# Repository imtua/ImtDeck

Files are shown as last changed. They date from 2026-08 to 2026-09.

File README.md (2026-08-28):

# ImtDeck - Your own Cyberdeck

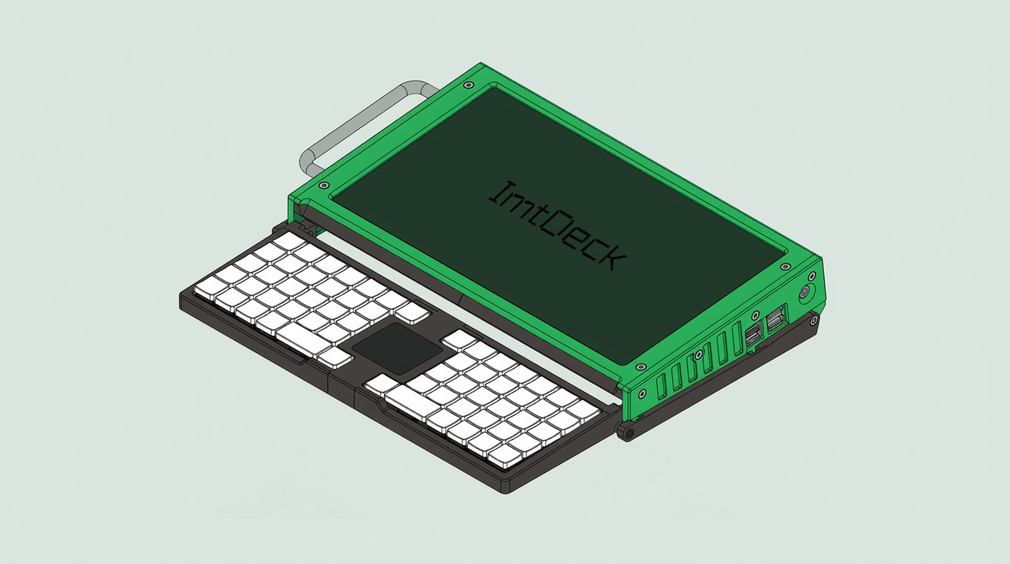
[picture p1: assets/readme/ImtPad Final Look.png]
Final Look of ImtDeck


ImtDeck, a cyberdeck designed by **Imtiaz Ahmed**. In ImtDeck, basic tasks and a light AI can be run easily. In this project, it technically contains 2 projects, **ImtDeck-Carrier** and **ImtKeeb-Ortho62**.

**Stardance** project: https://stardance.hackclub.com/projects/54966

# Wanted Ingredients to craft ImtDeck
## Main items-
- **Lattepanda MU + Carrier + Active Cooler** - $250.00 - 1
- **11.6 Inch Screen** - $129.00 - 1
- **Antenna** - $7.99 - 1
- **Audio Card from Waveshare** - $51.71 - 1
- **KAILH Linear Low Profile Switches** - $56.82 - 3
- **Chosfox CFX BoW Keycap Set** - $33.00 - 1
- **TPS43-201A-S** - $13.87 - 1
- **Power Bank** - $13.00 - 1
- **WIFI Card** - $28.00 - 1
- **Pi Pico** - $12.00 - 1
- **USB Micro Cord** - $13.00 - 1
- **40MM Speaker** - $6.00 - 1
- **Tiny SSD** - $70.00 - 1

Check <a href="https://github.com/imtua/ImtDeck/blob/main/ImtDeck%20BOM.csv"><b>ImtDeck BOM.csv</b></a> for links.

## Hardwares-
- 4x M4 Threaded heat-set brass inserts
- 26x M3 Threaded heat-set brass inserts
- 6x M3x8mm Tapered head bolts
- 8x M3x12mm Tapered head bolts
- 4x M3x8mm Socket head bolts
- 4x M3x10mm Socket head bolts
- 2x M4x14mm Socket head bolts
- 2x M4x16mm Socket head bolts
- 2x M4x24mm Socket head bolts
- 1x 7mm OD Carbon fiber rod, 310mm long (can be any material)
- 2x 6.5x2.5mm neodymium magnets (optional)
- 1x Cabinet handle with 4-inch spacing between ends (optional)

# ImtKeeb-Ortho62 - Designed Keyboard for ImtDeck
**ImtKeeb-Ortho62** is a low-profile ortholinear 62 key keyboard that contains a trackpad in it.

**PCB of ImtKeeb-Ortho62:**

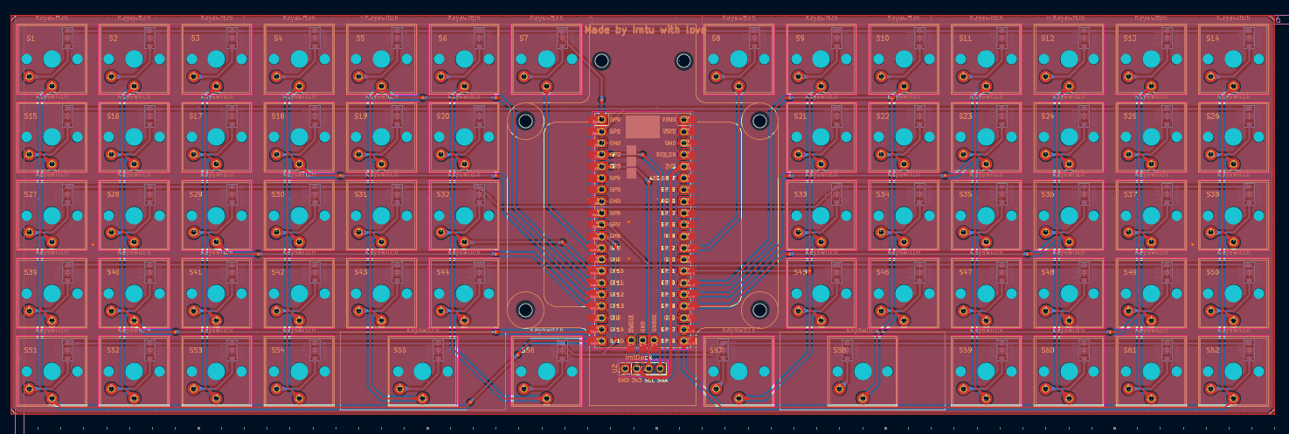
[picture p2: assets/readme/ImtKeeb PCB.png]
PCB of ImtKeeb-Ortho62


**3D PCB of ImtKeeb-Ortho62:**

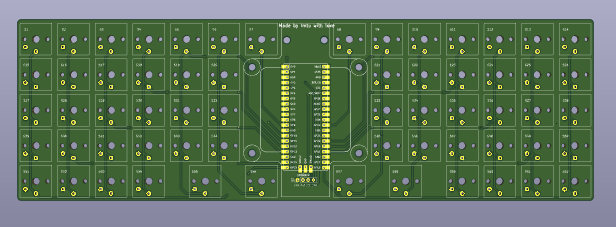
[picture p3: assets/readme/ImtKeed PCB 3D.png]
3D PCB of ImtKeeb-Ortho62


**ImtKeeb-Ortho62 will feature-**
- <a href="https://www.amazon.com/dp/B0B3MN1ZLW"><b>KAILH Low Profile Switch 1350 Chocolate</b></a> - 62 Switches.
- <a href="https://chosfox.com/collections/keycaps/products/chocfox-bow"><b>Chosfox CFX BoW Keycap Set</b></a> - 62 Keycaps.
- <a href="https://www.digikey.com/en/products/detail/azoteq-pty-ltd/TPS43-201A-S/7164940"><b>TPS43-201A-S</b></a> Trackpad.
- <a href="https://store.roboticsbd.com/raspberry-pi/1599-raspberry-pi-pico-robotics-bangladesh.html"><b>Raspberry Pi Pico</b></a> - Brain of the ImtKeeb-Ortho62.

**Files of ImtKeeb-Ortho62**
- <a href="https://github.com/imtua/ImtDeck/blob/main/production/ImtKeeb-Ortho62/ImtKeeb-Ortho62%20Gerber.zip"><b>ImtKeeb-Ortho62 Gerber Files</a></b> - **/Production/ImtKeeb-Ortho62/ImtKeeb-Ortho62 Gerber.zip**
- <a href="https://github.com/imtua/ImtDeck/blob/main/PCB/ImtKeeb-Ortho62/ImtKeed-Ortho62.kicad_sch"><b>ImtKeeb-Ortho62 Schematics</a><b> - **/PCB/ImtKeeb-Ortho62/ImtKeed-Ortho62.kicad_sch**
- <a href="https://github.com/imtua/ImtDeck/blob/main/PCB/ImtKeeb-Ortho62/ImtKeeb-Ortho62.kicad_pcb"><b>ImtKeeb-Ortho62 PCB</a></b> - **/PCB/ImtKeeb-Ortho62/ImtKeed-Ortho62.kicad_pcb**
- <a href="https://github.com/imtua/ImtDeck/tree/main/QMK"><b>Keyboard QMK config files</b></a> - /QMK

This can be used without the ImtDeck.

# ImtDeck-Carrier - Carrier for MU LattePanda
**ImtDeck-Carrier** is a carrier that holds the lattepanda and makes it route and connect to devices like the monitor, fan, keyboard etc.

**Schematic of ImtDeck-Carrier:**

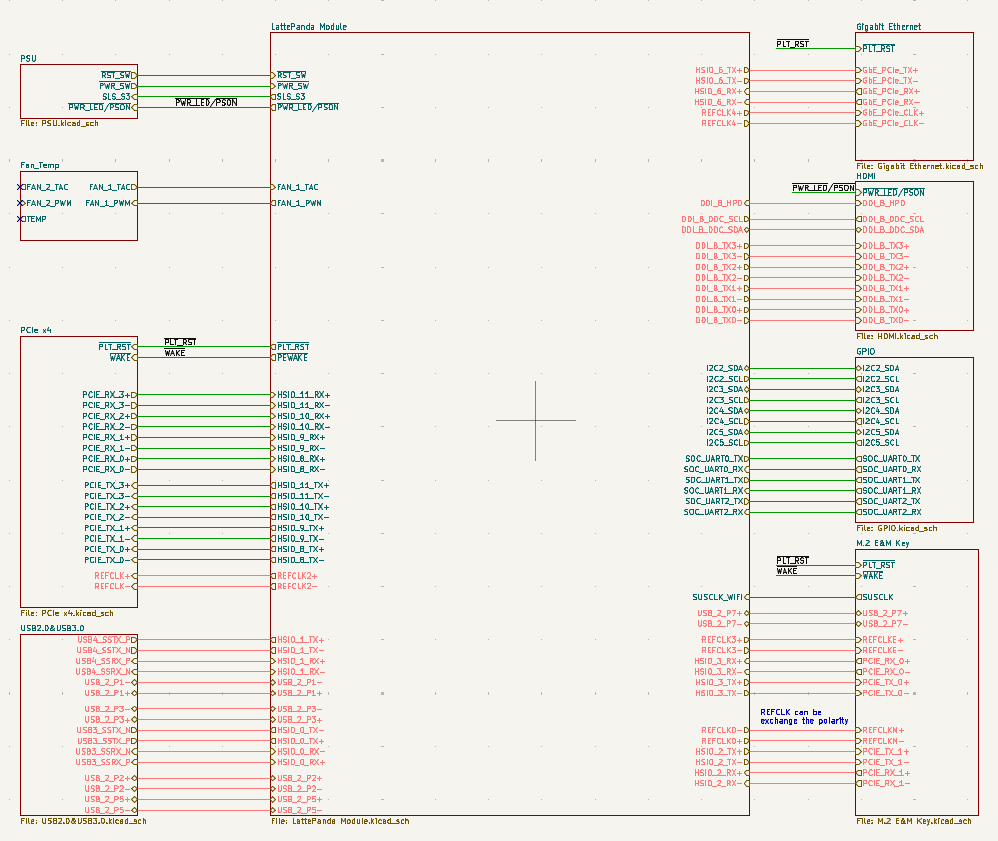
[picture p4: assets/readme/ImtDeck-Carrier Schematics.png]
Schematic of ImtDeck-Carrier


**PCB of ImtDeck-Carrier:**

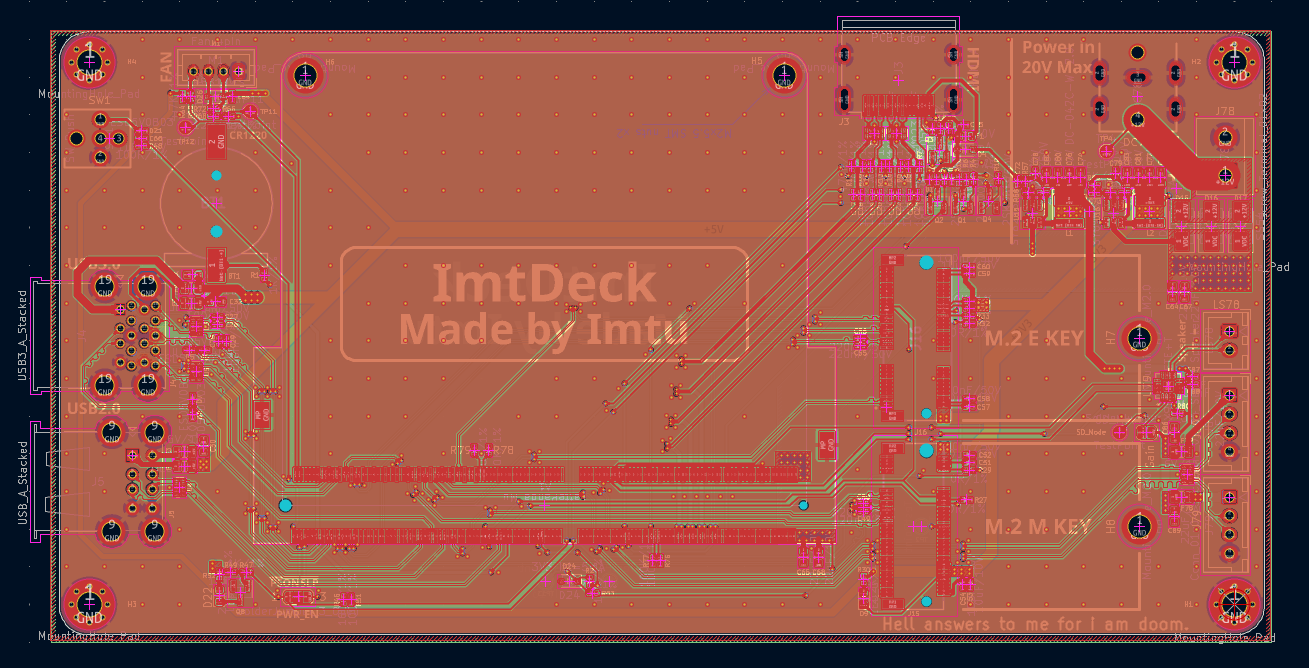
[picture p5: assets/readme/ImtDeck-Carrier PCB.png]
PCB of ImtDeck-Carrier


**ImtDeck-Carrier** will hold the Lattepanda MU in its place and will distribute powers between items. 

**Files of ImtKeeb-Ortho62**
- <a href="https://github.com/imtua/ImtDeck/blob/main/production/ImtDeck-Carrier/ImtDeck-Carrier%20Gerber.zip"><b>ImtDeck-Carrier Gerber Files</a></b> - **/Production/ImtDeck-Carrier/ImtDeck-Carrier Gerber.zip**
- <a href="https://github.com/imtua/ImtDeck/blob/main/PCB/ImtDeck-Carrier/ImtDeck-Carrier.kicad_sch"><b>ImtDeck-Carrier Schematics</a><b> - **/PCB/ImtDeck-Carrier/ImtDeck-Carrier.kicad_sch**
- <a href="https://github.com/imtua/ImtDeck/blob/main/PCB/ImtDeck-Carrier/ImtDeck-Carrier.kicad_pcbb"><b>ImtDeck-Carrier PCB</a></b> - **/PCB/ImtDeck-Carrier/ImtDeck-Carrier.kicad_pcb**

# Features
- ImtDeck will feature Linux Mint OS in it.
- With it, you can access different tools and a lightweight offline AI in it.
- All ready-to-go device.
- Can play low-end games on it.
- Features Keyboard and Trackpad.
- Sound System.
- Can run everything a normal laptop can.

# Conclusion

Made by <a href="https://github.com/imtua"><b>Imtiaz</b></a> with the help of <a href="https://hackclub.com"><b>Hack Club</a></b>

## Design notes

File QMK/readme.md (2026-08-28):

# ImtKeeb-Ortho62

*This keyboard was designed for use in ImtDeck. can be used without ImtDeck, not for business purposes.

* Keyboard Maintainer: [Imtiaz Ahamed](https://github.com/imtua)
* Hardware Supported: *Pi-Pico/RP2040*
* Hardware Availability: Any Hardware Shop.

Make example for this keyboard (after setting up your build environment):

    make imtkeeb-ortho62:default

Flashing example for this keyboard:

    make imtkeeb-ortho62:default:flash

See the [build environment setup](https://docs.qmk.fm/#/getting_started_build_tools) and the [make instructions](https://docs.qmk.fm/#/getting_started_make_guide) for more information. Brand new to QMK? Start with our [Complete Newbs Guide](https://docs.qmk.fm/#/newbs).

## Bootloader

Enter the bootloader in 3 ways:

* **Bootmagic reset**: Hold down the key at (0,0) in the matrix (usually the top left key or Escape) and plug in the keyboard.
* **Physical reset button**: Briefly press the button on the back of the PCB - some may have pads you must short instead.
* **Keycode in layout**: Press the key mapped to `QK_BOOT` if it is available.

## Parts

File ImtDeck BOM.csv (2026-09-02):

Item Name | Qty | Price (total) (USD) | Item link | Notes
Lattepanda MU | 1 | $199.00 | https://www.dfrobot.com/product-2901.html | Brain ImtDeck
Active Cooler | 1 | $12.00 | https://www.dfrobot.com/product-2901.html | Active Cooler
Carrier Board | 1 | $39.00 | https://www.dfrobot.com/product-2901.html | Carrier
PCB | $70.00 | jlcpcb.com | pcb grant
11.6 Inch Screen | 1 | $129.00 | https://www.dfrobot.com/product-2794.html | Main Display (Touch Display)
Antenna | 1 | $7.99 | https://www.amazon.com/dp/B07DB5VWS1 | Antenna needed for ImtDeck
Audio Card from Waveshare | 1 | $51.71 | https://www.waveshare.com/usb-to-audio.htm | With Shipping Costs
KAILH Linear Low Profile Switches | 3 | $56.82 | https://www.amazon.com/dp/B0B3MN1ZLW | Switches
Chosfox CFX BoW Keycap Set | 1 | $33.00 | https://chosfox.com/products/chocfox-bow?variant=43187789955266 | Keycaps
TPS43-201A-S | 1 | $13.87 | https://www.aliexpress.com/item/1005010179756077.html | Trackpad
Power Bank | 1 | $13.00 | Will buy from local shops | Powerbank
WIFI Card | 1 | $28.00 | Will buy from local shops | WIFI Card
Pi Pico | 1 | $12.00 | Will buy from local shops | Pi Pico
USB Micro Cord | 1 | $13.00 | Will buy from local shops | USB Micro Cord
40MM Speaker | 1 | $6.00 | Will buy from local shops | 40MM Speaker
Tiny SSD | 1 | $70.00 | Will buy from local shops | Tiny SSD
Total Price (USD): | $754.39

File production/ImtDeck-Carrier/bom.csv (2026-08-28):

Designator | Footprint | Quantity | Value | LCSC Part #
A1 | LattePanda_Module_H8.0mm_Horizontal | 1 | LattePanda_Mu | C2761395
BT1 | Battery_Holder_CR1220_S8411-45R | 1 | Battery_Cell | C964723
C17, C18, C19, C20, C21, C22, C23, C24, C25, C26, C27, C28, C29, C52, C54, C58, C60, C70, C71, C78, C79, C84 | 0402 | 22 | 100nF/50V
C30, C31, C32, C64, C65, C67, C68, C74, C75, C76, C77, C80, C81, C82, C83, C86, C89 | 0603 | 17 | 22uF/10V
C49, C50, C55, C56 | 0402 | 4 | 220nF/50V
C51, C53, C57, C59 | 0402 | 4 | 10uF/10V
C66 | 0402 | 1 | 1uF/16V
C87 | 0402 | 1 | 10uF
C88 | 0402 | 1 | 100nF
D1, D2, D21, D3, D5, D6, D7, D8 | 0402 | 8 | ESD5V0B03 | C521894
D15, D16, D17 | D_SMA | 3 | SS54 | C5200096
D22, D9 | 0603 | 2 | LED_G
D24 | D_SOD-323 | 1 | 3V3 Izt=5mA | SOD-323
D26, D4 | D_SOD-323 | 2 | 1N5819WS | C191023
DC78 | DC-IN-TH_DC-042C-W-2.0 | 1 | DC-042C-W-2.0 | C381108
F1 | 0603 | 1 | 6V/50mA | C7472508
F2, F3, F78, F79 | 0805 | 4 | 6V/1A | C883108
F4 | 0805 | 1 | 6V/2A | C883112
F5 | 0805 | 1 | 6V/2A | C883108
H5, H6 | MountingHole_3mm_M2_Pad_TopOnly | 2 | MountingHole_Pad | C5301799
H7, H8 | MountingHole_3mm_M2_Pad_TopOnly | 2 | MountingHole_M2.0 | C5301801
J15 | PCIe_M.2_Connectors_P=0.5mm_H=4.2mm_KeyM | 1 | Bus_M.2_Socket_M | C7498140
J16 | PCIe_M.2_Connectors_P=0.5mm_H=4.2mm_KeyE | 1 | Bus_M.2_Socket_E | C7498141
J3 | HDMI_A_Molex_208658-1001_Horizontal | 1 | HDMI_A | C2906135
J4 | USB3_A_Molex_48406-0001_Horizontal_Stacked | 1 | USB3_A_Stacked | C2895028
J5 | USB_A_CUI_UJ2-ADH-TH_Horizontal_Stacked | 1 | USB_A_Stacked | C7527675
J78 | TerminalBlock_bornier-2_P5.08mm | 1 | Screw_Terminal_01x02 | C394556
J79, J80 | JST_XH_B4B-XH-A_1x04_P2.50mm_Vertical | 2 | Conn_01x04_Socket | C144395
L1, L2 | L_Sunlord_SWPA4020S | 2 | 2.2uH/4.3A | C3222957
LS78 | JST_XH_B2B-XH-A_1x02_P2.50mm_Vertical | 1 | Speaker | C495685
M1 | JST_PH_B4B-PH-K_1x04_P2.00mm_Vertical | 1 | Fan_4pin | C131334
Q1, Q8 | SOT-23 | 2 | 2N7002 | C727148
Q2, Q3, Q4 | SOT-23 | 3 | 2SK3018 | C727148
R1, R11, R47 | 0402 | 3 | 1K/1%
R10, R13, R14, R16, R17, R7, R8, R9 | 0402 | 8 | 470R/1%
R15, R18, R19, R3, R30, R5, R52, R53 | 0402 | 8 | 2.2K/1%
R2, R34, R35, R49, R58, R78, R79 | 0402 | 7 | 10K/1%
R27, R29, R32, R33 | 0402 | 4 | 0R/1%
R4 | 0402 | 1 | 1M/1%
R46, R48, R69 | 0402 | 3 | 100R/1%
R51, R76, R77 | 0402 | 3 | 100K/1%
R57 | 0402 | 1 | 75K/1%
R59, R6, R68 | 0402 | 3 | 21.5K/1%
R60, R72 | 0402 | 2 | 4.7K/1%
R80 | 0402 | 1 | 1M
SW1 | SW-TH_TM-007-D1-A-03 | 1 | SW_Push | C5184999
TP2, TP4 | TestPoint_Pad_D1.5mm | 2 | TestPoint
U1, U2 | Diodes_UDFN-10_1.0x2.5mm_P0.5mm | 2 | TPAZ1023-04F | C1980462
U15, U16 | TSOT-23-6 | 2 | SY8253ADC | C93736
U3, U4, U5, U78 | Diodes_UDFN-10_1.0x2.5mm_P0.5mm | 4 | ULC0524P | C1980462
U79 | 21-0136I_T1633-4_MXM | 1 | MAX98357AETE+T | C910544

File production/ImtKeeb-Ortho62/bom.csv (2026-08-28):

Designator | Footprint | Quantity | Value | LCSC Part #
D1, D10, D11, D12, D13, D14, D15, D16, D17, D18, D19, D2, D20, D21, D22, D23, D24, D25, D26, D27, D28, D29, D3, D30, D31, D32, D33, D34, D35, D36, D37, D38, D39, D4, D40, D41, D42, D43, D44, D45, D46, D47, D48, D49, D5, D50, D51, D52, D53, D54, D55, D56, D57, D58, D59, D6, D60, D61, D62, D7, D8, D9 | Diode_SOD-123 | 62 | Diode | 1N4148W-7-F

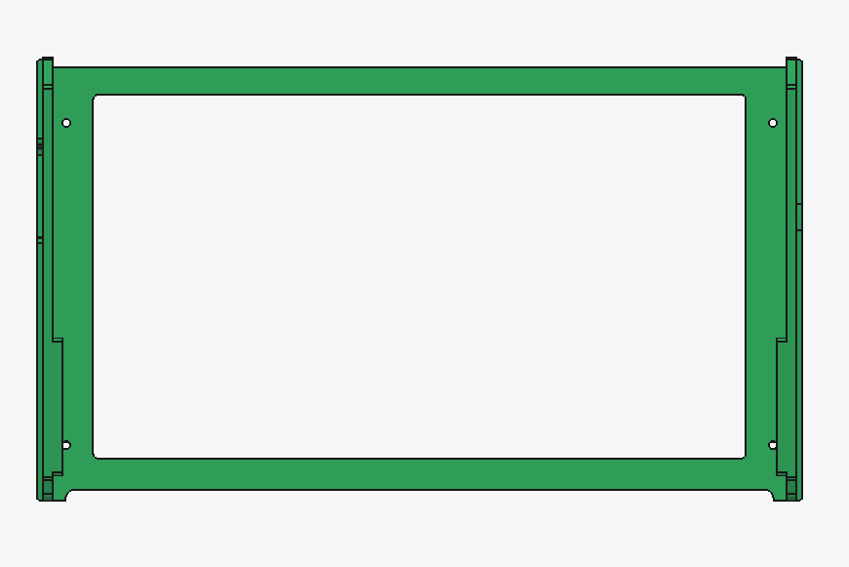
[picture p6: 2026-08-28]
assets/readme/ImtDeck Metal Parts.png

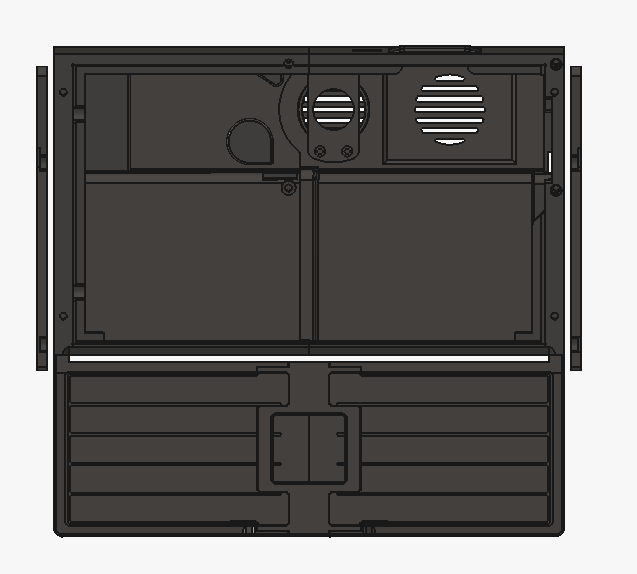
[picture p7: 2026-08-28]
assets/readme/ImtDeck Printed Parts.png

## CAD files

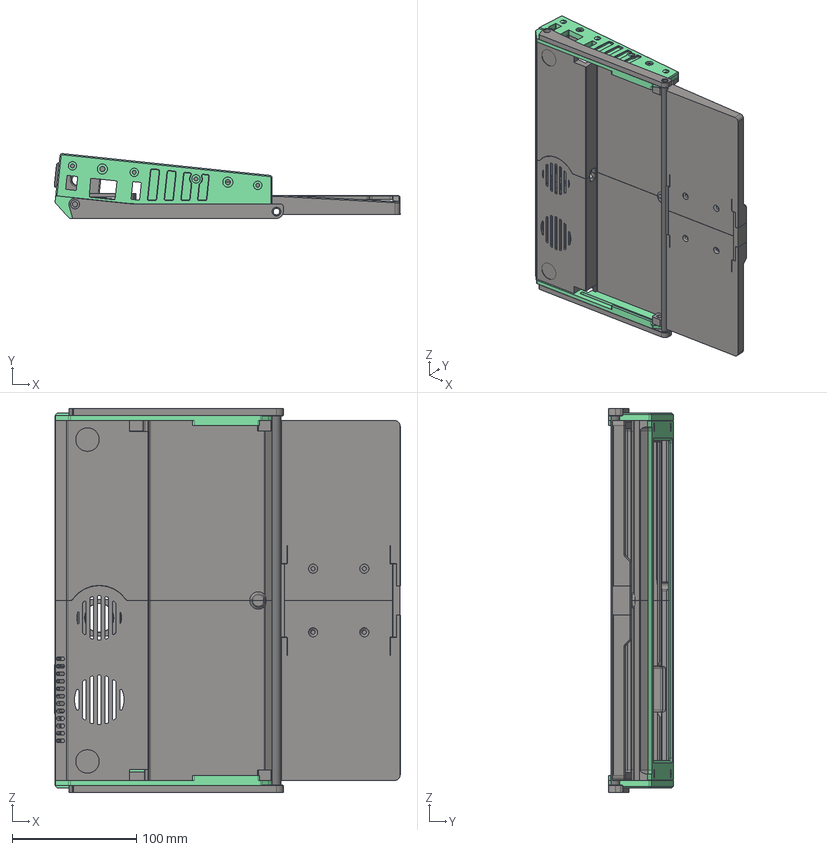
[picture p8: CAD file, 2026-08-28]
3D Files/ImtDeck Case.step
278.9 x 52.2 x 309.2 mm
3-Part-Frame
left-body-wall
left-body-wall(Mirror)
body-section
Upper_Front-Plate
speaker-cap
stand(Mirror) (2)
tube
stand

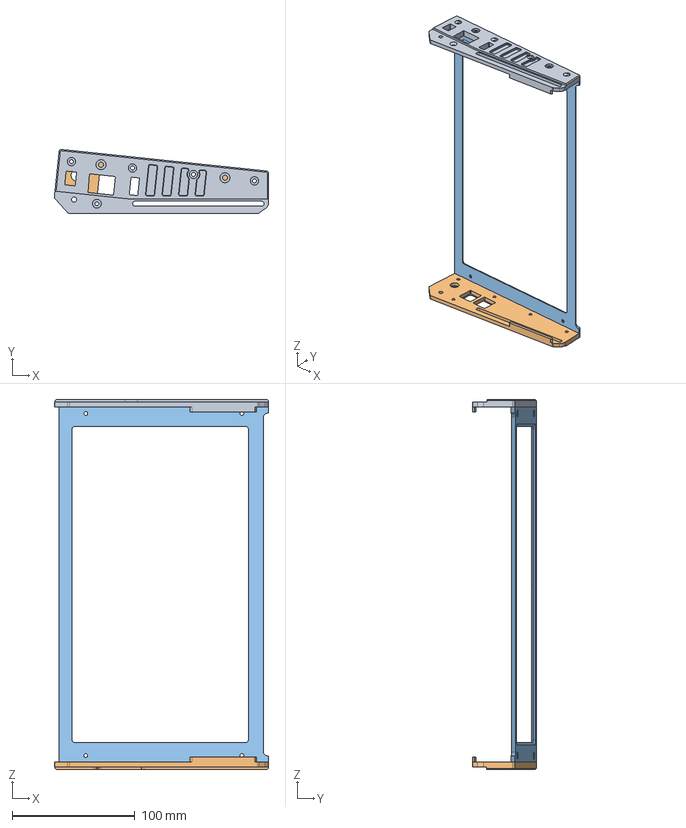
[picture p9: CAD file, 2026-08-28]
3D Files/ImtDeck Metal Parts.step
174.7 x 52.2 x 301.6 mm
left-body-wall
left-body-wall(Mirror)
Upper_Front-Plate

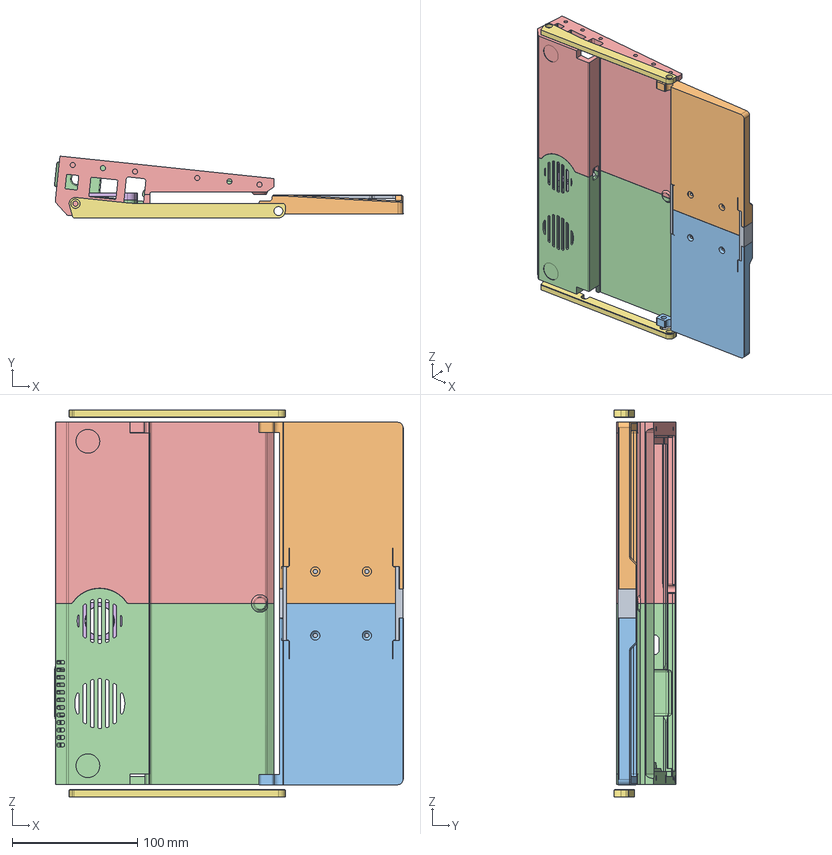
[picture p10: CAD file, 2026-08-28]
3D Files/ImtDeck Printed Parts.step
278.9 x 49.4 x 309.2 mm
3-Part-Frame
body-section
speaker-cap
stand(Mirror) (2)
stand

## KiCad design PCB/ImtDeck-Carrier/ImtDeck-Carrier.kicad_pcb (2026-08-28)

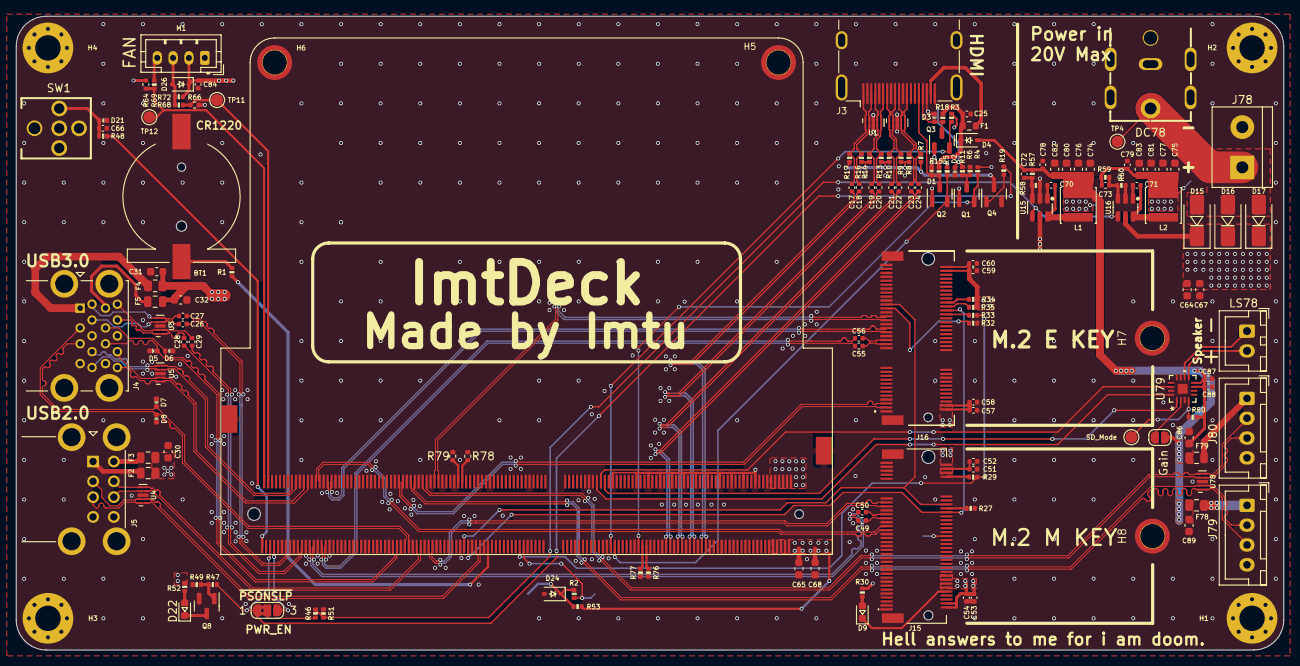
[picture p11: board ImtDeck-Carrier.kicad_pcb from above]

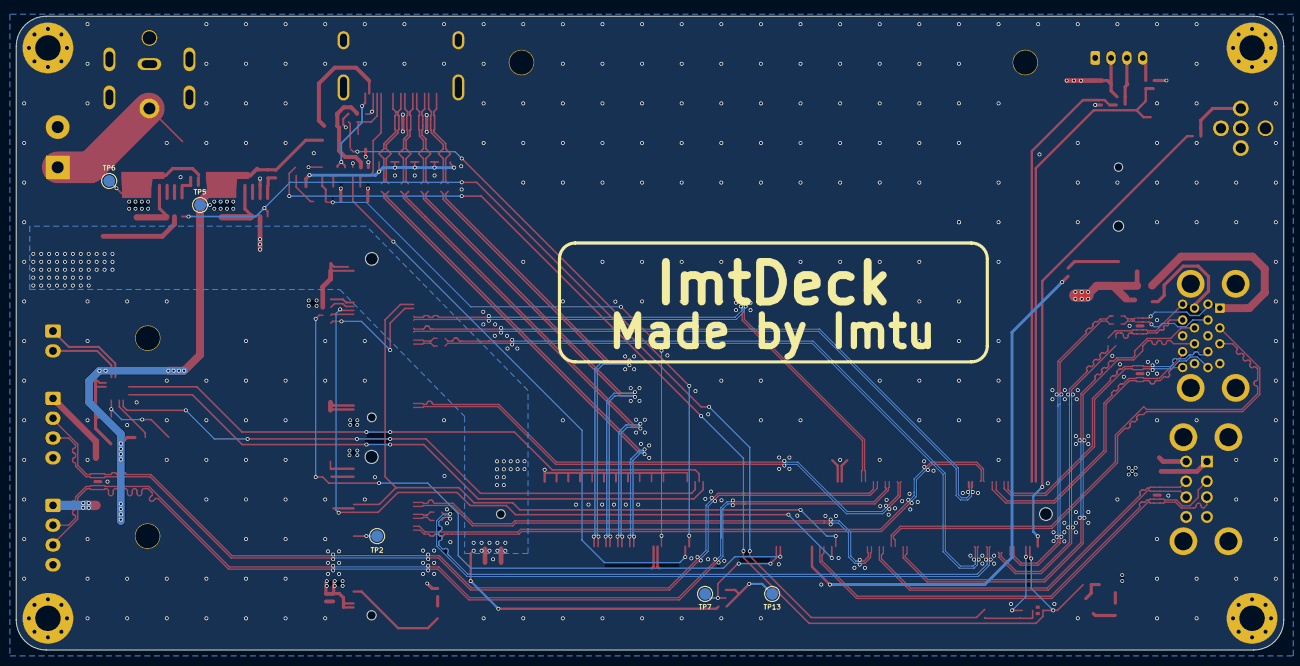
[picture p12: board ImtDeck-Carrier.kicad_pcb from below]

Board: 4 copper layers, 160.0 x 80.0 mm, 170 parts (5 on the bottom side), 126 nets.

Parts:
A1: LattePanda_Mu; LattePanda_Module_H8.0mm_Horizontal
BT1: Battery_Cell; Battery_Holder_CR1220_S8411-45R
C17, C18, C19, C20, C21, C22, C23, C24, C25, C26, C27, C28, C29, C52, C54, C58, C60, C70, C71, C78, C79, C84: 100nF/50V; C_0402_1005Metric
C30, C31, C32, C64, C65, C67, C68, C74, C75, C76, C77, C80, C81, C82, C83, C86, C89: 22uF/10V; C_0603_1608Metric
C49, C50, C55, C56: 220nF/50V; C_0402_1005Metric
C51, C53, C57, C59: 10uF/10V; C_0402_1005Metric
C66: 1uF/16V; C_0402_1005Metric
C72, C73: 12pF/50V; C_0402_1005Metric
C87: 10uF; C_0402_1005Metric
C88: 100nF; C_0402_1005Metric
D1, D2, D3, D5, D6, D7, D8, D21: ESD5V0B03; D_0402_1005Metric
D4, D26: 1N5819WS; D_SOD-323
D9, D22: LED_G; LED_0603_1608Metric
D15, D16, D17: SS54; D_SMA
D24: 3V3 Izt=5mA; D_SOD-323
DC78: DC-042C-W-2.0; DC-IN-TH_DC-042C-W-2.0
F1: 6V/50mA; R_0603_1608Metric
F2, F3, F78, F79: 6V/1A; Fuse_0805_2012Metric
F4: 6V/2A; R_0805_2012Metric
F5: 6V/2A; Fuse_0805_2012Metric
Gain: SolderJumper_2_Open; SolderJumper-2_P1.3mm_Open_RoundedPad1.0x1.5mm
H1, H2, H3, H4: MountingHole_Pad; MountingHole_3.2mm_M3_Pad_Via
H5, H6: MountingHole_Pad; MountingHole_3mm_M2_Pad_TopOnly
H7, H8: MountingHole_M2.0; MountingHole_3mm_M2_Pad_TopOnly
J3: HDMI_A; HDMI_A_Molex_208658-1001_Horizontal
J4: USB3_A_Stacked; USB3_A_Molex_48406-0001_Horizontal_Stacked
J5: USB_A_Stacked; USB_A_CUI_UJ2-ADH-TH_Horizontal_Stacked
J15: Bus_M.2_Socket_M; PCIe_M.2_Connectors_P=0.5mm_H=4.2mm_KeyM
J16: Bus_M.2_Socket_E; PCIe_M.2_Connectors_P=0.5mm_H=4.2mm_KeyE
J78: Screw_Terminal_01x02; TerminalBlock_bornier-2_P5.08mm
J79, J80: Conn_01x04_Socket; JST_XH_B4B-XH-A_1x04_P2.50mm_Vertical
JP79: SolderJumper_3_Open; SolderJumper-3_P1.3mm_Bridged2Bar12_RoundedPad1.0x1.5mm_Num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
L1, L2: 2.2uH/4.3A; L_Sunlord_SWPA4020S
LS78: Speaker; JST_XH_B2B-XH-A_1x02_P2.50mm_Vertical
M1: Fan_4pin; JST_PH_B4B-PH-K_1x04_P2.00mm_Vertical
Q1, Q8: 2N7002; SOT-23
Q2, Q3, Q4: 2SK3018; SOT-23
R1, R11, R47: 1K/1%; R_0402_1005Metric
R2, R34, R35, R49, R58, R78, R79: 10K/1%; R_0402_1005Metric
R3, R5, R15, R18, R19, R30, R52, R53: 2.2K/1%; R_0402_1005Metric
R4: 1M/1%; R_0402_1005Metric
R6, R59, R66, R68: 21.5K/1%; R_0402_1005Metric
R7, R8, R9, R10, R13, R14, R16, R17: 470R/1%; R_0402_1005Metric
R27, R29, R32, R33: 0R/1%; R_0402_1005Metric
R46, R48, R69: 100R/1%; R_0402_1005Metric
R51, R76, R77: 100K/1%; R_0402_1005Metric
R57: 75K/1%; R_0402_1005Metric
R60, R64, R72: 4.7K/1%; R_0402_1005Metric
R80: 1M; R_0402_1005Metric
SD_Mode: TestPoint; TestPoint_Pad_D1.5mm
SW1: SW_Push; SW-TH_TM-007-D1-A-03
TP2, TP4, TP5, TP6, TP7, TP11, TP12, TP13: TestPoint; TestPoint_Pad_D1.5mm
U1, U2: TPAZ1023-04F; Diodes_UDFN-10_1.0x2.5mm_P0.5mm
U3, U4, U5, U78: ULC0524P; Diodes_UDFN-10_1.0x2.5mm_P0.5mm
U15, U16: SY8253ADC; TSOT-23-6
U79: MAX98357AETE+T; 21-0136I_T1633-4_MXM

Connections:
5V_HDMI_VCC: C25.1, D4.1 (K), F1.1, R15.1, R18.1
+3V3: C51.2, C52.2, C53.2, C54.2, C57.2, C58.2, C59.2, C60.2, C73.1, C75.2, C77.2, C79.1, C81.2, C83.2, J15.2 (3.3V), J15.4 (3.3V), J15.12 (3.3V), J15.14 (3.3V), J15.16 (3.3V), J15.18 (3.3V), J15.70 (3.3V), J15.72 (3.3V), J15.74 (3.3V), J16.2 (3.3V), J16.4 (3.3V), J16.72 (3.3V), J16.74 (3.3V), L2.2, Q1.1 (G), Q2.1 (G), Q3.1 (G), R3.1, R4.1, R5.1, R30.2, R34.2, R35.1, R52.2, R59.2, R64.1, TP6.1
+5V: C30.2, C31.2, C32.2, C72.1, C74.2, C76.2, C78.1, C80.2, C82.2, C84.1, C86.2, C87.1, C88.1, C89.2, D4.2 (A), D26.1 (K), F2.1, F3.1, F4.1, F5.1, F78.1, F79.1, Gain.1 (A), L1.2, M1.2 (+), R57.2, R72.1, R80.1, TP5.1, U79.7 (VDD), U79.8 (VDD)
+12V: D15.2 (A), D16.2 (A), D17.2 (A), DC78.4, J78.1, TP4.1
+BATT: A1.115 (VBAT), R1.1
/Fan_Temp/FAN_1_PWM: A1.2 (FAN1_PWM), R64.2, R69.1, TP12.1
/Fan_Temp/FAN_1_TAC: A1.4 (FAN1_TAC), R66.1, R68.2, TP11.1
/HDMI/DDC_SCL: D1.2 (A2), J3.15 (SCL), Q2.3 (D), R15.2
/HDMI/DDC_SDA: D3.2 (A2), J3.16 (SDA), Q3.3 (D), R18.2
/HDMI/DDI_B_DDC_SCL: A1.171 (DDIB_DDC_SCL), Q2.2 (S), R5.2
/HDMI/DDI_B_DDC_SDA: A1.169 (DDIB_DDC_SDA), Q3.2 (S), R3.2
/HDMI/DDI_B_HPD: A1.183 (DDIB_HPD), Q1.2 (S), R4.2
/HDMI/DDI_B_TX0+: A1.217 (DDIB_TX0+), C17.1
/HDMI/DDI_B_TX0-: A1.215 (DDIB_TX0-), C18.1
/HDMI/DDI_B_TX1+: A1.211 (DDIB_TX1+), C19.1
/HDMI/DDI_B_TX1-: A1.209 (DDIB_TX1-), C20.1
/HDMI/DDI_B_TX2+: A1.205 (DDIB_TX2+), C21.1
/HDMI/DDI_B_TX2-: A1.203 (DDIB_TX2-), C22.1
/HDMI/DDI_B_TX3+: A1.199 (DDIB_TX3+), C23.1
/HDMI/DDI_B_TX3-: A1.197 (DDIB_TX3-), C24.1
/HDMI/HPD: D2.2 (A2), J3.19 (HPD), R11.2
/HDMI/TMDS_CK+: C23.2, J3.10 (CK+), R8.1, U2.4, U2.7 (NC)
/HDMI/TMDS_CK-: C24.2, J3.12 (CK-), R7.1, U2.5, U2.6 (NC)
/HDMI/TMDS_D0+: C21.2, J3.7 (D0+), R10.1, U2.1, U2.10 (NC)
/HDMI/TMDS_D0-: C22.2, J3.9 (D0-), R9.1, U2.2, U2.9 (NC)
/HDMI/TMDS_D1+: C19.2, J3.4 (D1+), R14.1, U1.4, U1.7 (NC)
/HDMI/TMDS_D1-: C20.2, J3.6 (D1-), R13.1, U1.5, U1.6 (NC)
/HDMI/TMDS_D2+: C17.2, J3.1 (D2+), R17.1, U1.1, U1.10 (NC)
/HDMI/TMDS_D2-: C18.2, J3.3 (D2-), R16.1, U1.2, U1.9 (NC)
/LattePanda Module/HSIO_0_TX+: A1.13 (HSIO0_TX+), C27.1
/LattePanda Module/HSIO_0_TX-: A1.15 (HSIO0_TX-), C26.1
/LattePanda Module/HSIO_1_TX+: A1.19 (HSIO1_TX+), C29.1
/LattePanda Module/HSIO_1_TX-: A1.21 (HSIO1_TX-), C28.1
/LattePanda Module/HSIO_2_RX+: A1.28 (HSIO2_RX+), J15.43 (PERp0/SATA-B-)
/LattePanda Module/HSIO_2_RX-: A1.30 (HSIO2_RX-), J15.41 (PERn0/SATA-B+)
/LattePanda Module/HSIO_2_TX+: A1.25 (HSIO2_TX+), C49.1
/LattePanda Module/HSIO_2_TX-: A1.27 (HSIO2_TX-), C50.1
/LattePanda Module/HSIO_3_RX+: A1.34 (HSIO3_RX+), J16.41 (PERp0)
/LattePanda Module/HSIO_3_RX-: A1.36 (HSIO3_RX-), J16.43 (PERn0)
/LattePanda Module/HSIO_3_TX+: A1.31 (HSIO3_TX+), C55.1
/LattePanda Module/HSIO_3_TX-: A1.33 (HSIO3_TX-), C56.1
/LattePanda Module/REFCLK0+: A1.85 (REFCLK0+), J15.53 (REFCLKn)
/LattePanda Module/REFCLK0-: A1.87 (REFCLK0-), J15.55 (REFCLKp)
/LattePanda Module/REFCLK3+: A1.88 (REFCLK3+), J16.47 (REFCLKp0)
/LattePanda Module/REFCLK3-: A1.90 (REFCLK3-), J16.49 (REFCLKn0)
/LattePanda Module/SLS_S3: A1.7 (SLS_S3), JP79.3 (B)
/LattePanda Module/SUSCLK_WIFI: A1.131 (SUSCLK), R29.2, R33.2
/LattePanda Module/USB_2_P7+: A1.70 (USB2_P4+), J16.3 (USB_D+)
/LattePanda Module/USB_2_P7-: A1.72 (USB2_P4-), J16.5 (USB_D-)
/LattePanda Module/~PWR_SW: A1.1 (~PWRBTN), R48.2
/M.2 E&M Key/CON_PCIE_TX_0+: C55.2, J16.35 (PETp0)
/M.2 E&M Key/CON_PCIE_TX_0-: C56.2, J16.37 (PETn0)
/M.2 E&M Key/CON_PCIE_TX_1+: C49.2, J15.49 (PETp0/SATA-A+)
/M.2 E&M Key/CON_PCIE_TX_1-: C50.2, J15.47 (PETn0/SATA-A-)
/M.2 E&M Key/~CLKREQE: J16.53 (~CLKREQ0), R32.1
/M.2 E&M Key/~CLKREQM: J15.52 (~CLKREQ), R27.1
/PSU/PWR_EN: R46.2, R51.2, U15.4 (EN), U16.4 (EN)
/USB2.0&USB3.0/CON_USB1_D_N: A1.109 (USB2_P5-), J5.2 (D1-), U4.2, U4.9 (NC)
/USB2.0&USB3.0/CON_USB1_D_P: A1.111 (USB2_P5+), J5.3 (D1+), U4.1, U4.10 (NC)
/USB2.0&USB3.0/CON_USB2_D_N: A1.79 (USB2_P3-), J5.6 (D2-), U4.5, U4.6 (NC)
/USB2.0&USB3.0/CON_USB2_D_P: A1.81 (USB2_P3+), J5.7 (D2+), U4.4, U4.7 (NC)
/USB2.0&USB3.0/CON_USB3_D_N: A1.73 (USB2_P2-), D8.2 (A2), J4.2 (D1-)
/USB2.0&USB3.0/CON_USB3_D_P: A1.75 (USB2_P2+), D7.2 (A2), J4.3 (D1+)
/USB2.0&USB3.0/CON_USB3_SSRX_N: A1.18 (HSIO0_RX-), J4.5 (SSRX1-), U5.4, U5.7 (NC)
/USB2.0&USB3.0/CON_USB3_SSRX_P: A1.16 (HSIO0_RX+), J4.6 (SSRX1+), U5.5, U5.6 (NC)
/USB2.0&USB3.0/CON_USB3_SSTX_N: C26.2, J4.8 (SSTX1-), U3.4, U3.7 (NC)
/USB2.0&USB3.0/CON_USB3_SSTX_P: C27.2, J4.9 (SSTX1+), U3.5, U3.6 (NC)
/USB2.0&USB3.0/CON_USB4_D_N: A1.67 (USB2_P1-), D6.2 (A2), J4.11 (D2-)
/USB2.0&USB3.0/CON_USB4_D_P: A1.69 (USB2_P1+), D5.2 (A2), J4.12 (D2+)
/USB2.0&USB3.0/CON_USB4_SSRX_N: A1.24 (HSIO1_RX-), J4.14 (SSRX2-), U5.1, U5.10 (NC)
/USB2.0&USB3.0/CON_USB4_SSRX_P: A1.22 (HSIO1_RX+), J4.15 (SSRX2+), U5.2, U5.9 (NC)
/USB2.0&USB3.0/CON_USB4_SSTX_N: C28.2, J4.17 (SSTX2-), U3.1, U3.10 (NC)
/USB2.0&USB3.0/CON_USB4_SSTX_P: C29.2, J4.18 (SSTX2+), U3.2, U3.9 (NC)
/~PLT_RST: A1.105 (~PLTRST), J15.50 (~PERST), J16.52 (~PERST0)
/~PWR_LED/~PSON: A1.5 (SLS_S0), JP79.1 (A), R19.1, R47.1
/~WAKE: A1.103 (~WAKE), J15.54 (~PEWAKE), J16.55 (~PEWAKE0)
Audio_Data: A1.166 (I2S_TXD), U79.1 (DIN)
BCLK: A1.162 (I2S_SCLK), U79.16 (BCLK)
GND: A1.11 (GND), A1.14 (GND), A1.17 (GND), A1.20 (GND), A1.23 (GND), A1.26 (GND), A1.29 (GND), A1.32 (GND), A1.35 (GND), A1.38 (GND), A1.41 (GND), A1.44 (GND), A1.47 (GND), A1.50 (GND), A1.53 (GND), A1.56 (GND), A1.59 (GND), A1.62 (GND), A1.65 (GND), A1.68 (GND), A1.71 (GND), A1.74 (GND), A1.77 (GND), A1.80 (GND), A1.83 (GND), A1.86 (GND), A1.89 (GND), A1.92 (GND), A1.95 (GND), A1.98 (GND), A1.101 (GND), A1.107 (GND), A1.110 (GND), A1.113 (GND), A1.116 (GND), A1.135 (GND), A1.136 (GND), A1.151 (GND), A1.158 (GND), A1.167 (GND), A1.170 (GND), A1.181 (GND), A1.182 (GND), A1.188 (GND), A1.189 (GND), A1.194 (GND), A1.195 (GND), A1.200 (GND), A1.201 (GND), A1.206 (GND), A1.207 (GND), A1.212 (GND), A1.213 (GND), A1.218 (GND), A1.219 (GND), A1.224 (GND), A1.225 (GND), A1.230 (GND), A1.231 (GND), A1.236 (GND), A1.237 (GND), A1.242 (GND), A1.243 (GND), A1.248 (GND), A1.249 (GND), A1.MP (Mountinge_Pads), BT1.2 (-), C25.2, C30.1, C31.1, C32.1, C51.1, C52.1, C53.1, C54.1, C57.1, C58.1, C59.1, C60.1, C64.1, C65.1, C66.2, C67.1, C68.1, C74.1, C75.1, C76.1, C77.1, C78.2, C79.2, C80.1, C81.1, C82.1, C83.1, C84.2, C86.1, C87.2, C88.2, C89.1, D1.1 (A1), D2.1 (A1), D3.1 (A1), D5.1 (A1), D6.1 (A1), D7.1 (A1), D8.1 (A1), D21.1 (A1), D24.2 (A), DC78.2, DC78.3, H1.1, H2.1, H3.1, H4.1, H5.1, H6.1, H7.1, H8.1, J3.2 (D2S), J3.5 (D1S), J3.8 (D0S), J3.11 (CKS), J3.17 (GND), J3.SH, J4.4 (GND1), J4.7 (DRAIN1), J4.13 (GND2), J4.16 (DRAIN2), J4.19 (SHIELD), J5.4 (GND1), J5.8 (GND2), J5.9 (Shield), J15.1 (GND), J15.3 (GND), J15.9 (GND), J15.15 (GND), J15.21 (GND), J15.27 (GND), J15.33 (GND), J15.39 (GND), J15.45 (GND), J15.51 (GND), J15.57 (GND), J15.71 (GND), J15.73 (GND), J15.75 (GND), J15.MP1, J15.MP2, J16.1 (GND), J16.7 (GND), J16.18 (GND), J16.33 (GND), J16.39 (GND), J16.45 (GND), J16.51 (GND), J16.57 (GND), J16.63 (GND), J16.69 (GND), J16.75 (GND), J16.MP1, J16.MP2, J78.2, J79.4, J80.4, M1.1 (-), Q4.2 (S), Q8.2 (S), R6.2, R27.2, R32.2, R49.1, R51.1, R58.1, R60.1, R66.2, R76.2, R77.2, R78.2, R79.2, SW1.2, U1.3 (VSS), U1.8 (VSS), U2.3 (VSS), U2.8 (VSS), U3.3 (VSS), U3.8 (VSS), U4.3 (VSS), U4.8 (VSS), U5.3 (VSS), U5.8 (VSS), U15.2 (GND), U16.2 (GND), U78.3 (VSS), U78.8 (VSS), U79.3 (GND), U79.11 (GND), U79.15 (GND), U79.17 (EPAD)
LRCLK: A1.164 (I2S_SFRM), U79.14 (LRCLK)
unnamed: A1.187 (TCP0_HPD), R76.1
unnamed: A1.185 (TCP1_HPD), R77.1
unnamed: A1.133 (~BIOS_SEL), R2.1, TP7.1
unnamed: A1.100 (~CLKREQ3), R79.1
unnamed: A1.102 (~CLKREQ4), R78.1
unnamed: BT1.1 (+), R1.2
unnamed: D9.2 (A), R30.1
unnamed: D9.1 (K), J15.10 (DAS/~DSS/~LED1)
unnamed: D22.2 (A), R52.1
unnamed: D22.1 (K), Q8.3 (D)
unnamed: D26.2 (A), M1.3 (Tacho), R68.1, R72.2
unnamed: F1.2, J3.18 (+5V)
unnamed: F4.2, J4.1 (VBUS1)
unnamed: F5.2, J4.10 (VBUS2)
unnamed: F2.2, J5.1 (VBUS1)
unnamed: F3.2, J5.5 (VBUS2)
unnamed: J15.38 (DEVSLP), TP2.1
unnamed: J15.68 (SUSCLK), R29.1
unnamed: J16.50 (SUSCLK), R33.1
unnamed: J16.56 (~W_DISABLE1), R34.1
unnamed: J16.54 (~W_DISABLE2), R35.2
unnamed: F78.2, J79.1
unnamed: F79.2, J80.1
unnamed: Gain.2 (B), U79.2 (GAIN_SLOT)
unnamed: JP79.2 (C), R46.1
unnamed: M1.4 (PWM), R69.2
unnamed: Q1.3 (D), R6.1, R11.1
unnamed: Q4.3 (D), R7.2, R8.2, R9.2, R10.2, R13.2, R14.2, R16.2, R17.2
unnamed: Q4.1 (G), R19.2
unnamed: Q8.1 (G), R47.2, R49.2
unnamed: C70.2, U15.1 (BOOST)
unnamed: C72.2, R57.1, R58.2, U15.3 (FB)
unnamed: C70.1, L1.1, U15.6 (SW)
unnamed: C71.2, U16.1 (BOOST)
unnamed: C73.2, R59.1, R60.2, U16.3 (FB)
unnamed: C71.1, L2.1, U16.6 (SW)
unnamed: R80.2, SD_Mode.1, U79.4 (*SD_MODE)
unnamed: LS78.1, U79.10 (OUTN)
unnamed: LS78.2, U79.9 (OUTP)
PWR: C66.1, D21.2 (A2), R48.1, SW1.1
USB_2_FP1+: A1.76 (USB2_P7+), J79.3, U78.1, U78.10 (NC)
USB_2_FP1-: A1.78 (USB2_P7-), J79.2, U78.2, U78.9 (NC)
USB_2_FP2+: A1.82 (USB2_P8+), J80.3, U78.4, U78.7 (NC)
USB_2_FP2-: A1.84 (USB2_P8-), J80.2, U78.5, U78.6 (NC)
VDC: A1.250 (VIN), A1.251 (VIN), A1.252 (VIN), A1.253 (VIN), A1.254 (VIN), A1.255 (VIN), A1.256 (VIN), A1.257 (VIN), A1.258 (VIN), A1.259 (VIN), A1.260 (VIN), C64.2, C65.2, C67.2, C68.2, D15.1 (K), D16.1 (K), D17.1 (K), R53.1, U15.5 (VIN), U16.5 (VIN)
VPullup: D24.1 (K), R2.2, R53.2, TP13.1

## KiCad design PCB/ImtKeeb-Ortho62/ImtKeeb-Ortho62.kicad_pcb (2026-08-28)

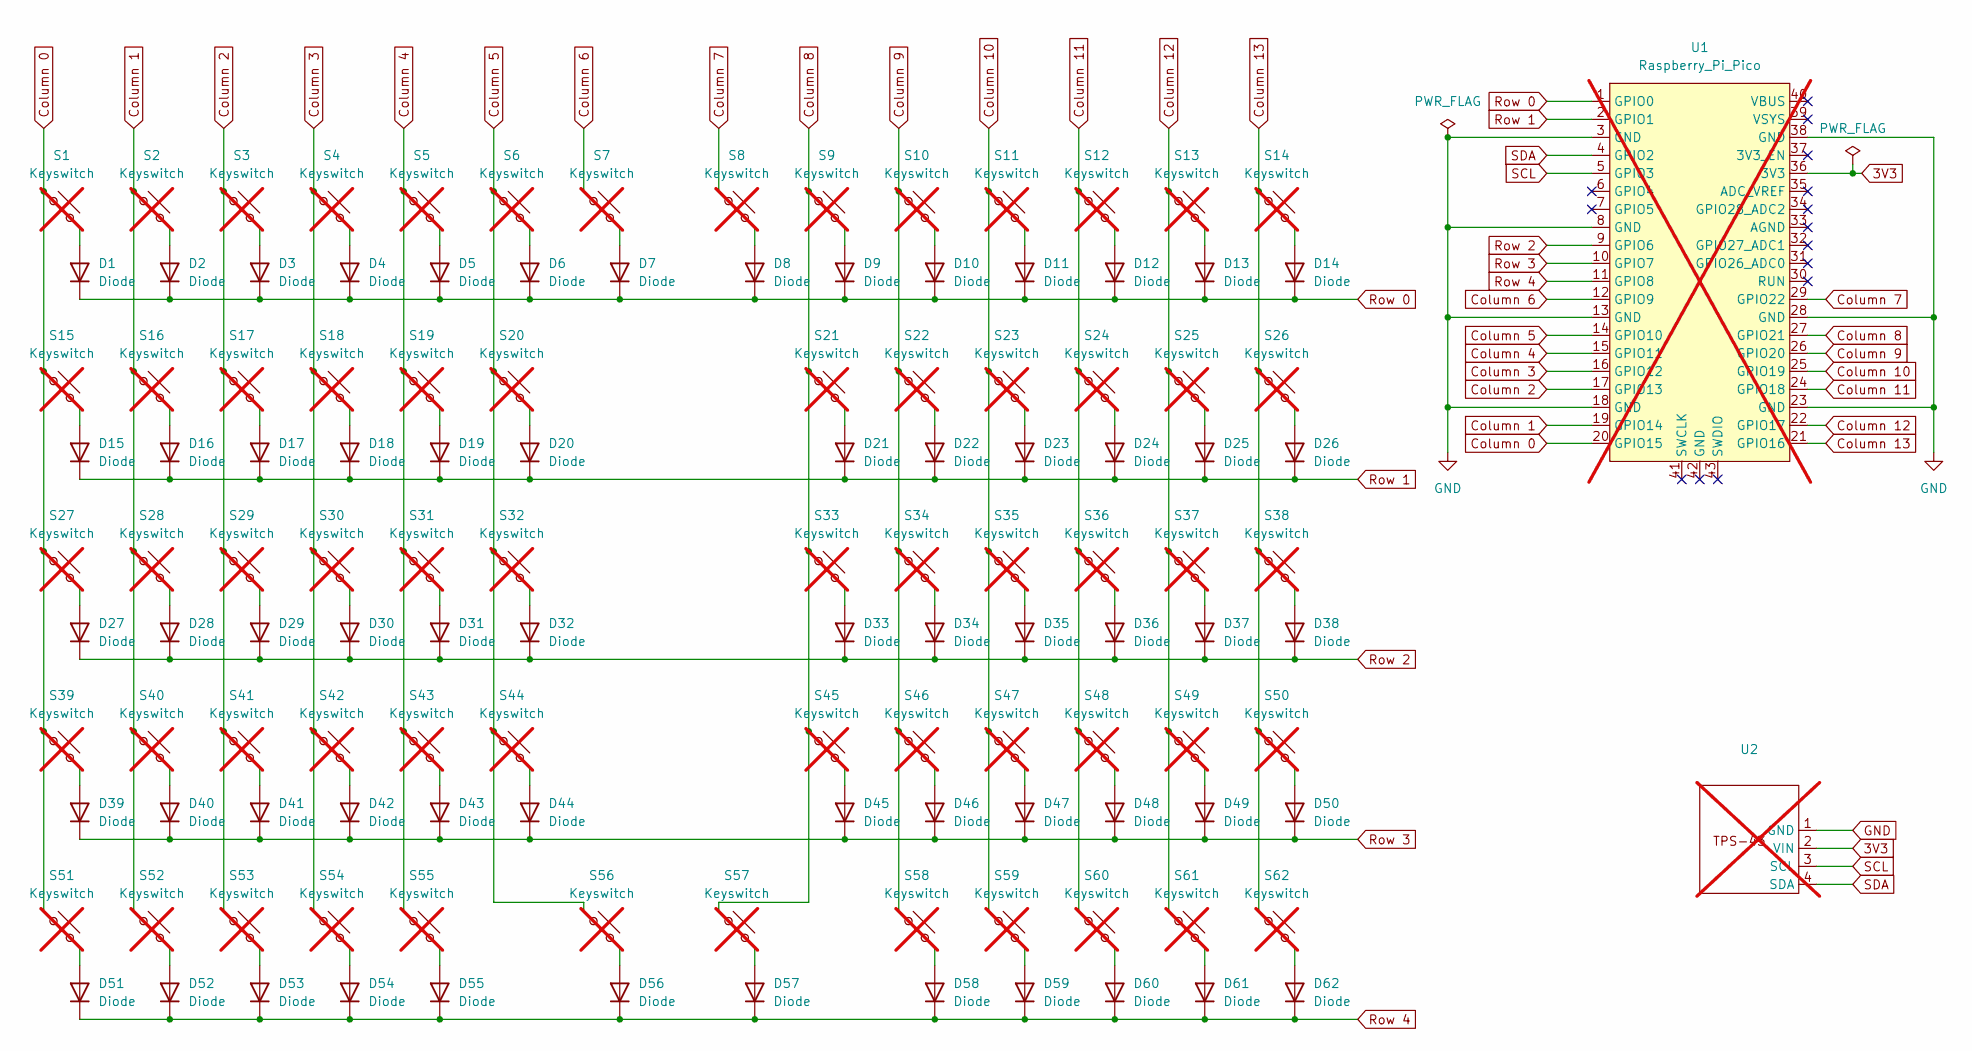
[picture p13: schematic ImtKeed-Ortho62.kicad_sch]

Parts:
D1, D2, D3, D4, D5, D6, D7, D8, D9, D10, D11, D12, D13, D14, D15, D16, D17, D18, D19, D20, D21, D22, D23, D24, D25, D26, D27, D28, D29, D30, D31, D32, D33, D34, D35, D36, D37, D38, D39, D40, D41, D42, D43, D44, D45, D46, D47, D48, D49, D50, D51, D52, D53, D54, D55, D56, D57, D58, D59, D60, D61, D62: Diode; Diode_SOD-123; MPN 1N4148W-7-F
S1, S2, S3, S4, S5, S6, S7, S8, S9, S10, S11, S12, S13, S14, S15, S16, S17, S18, S19, S20, S21, S22, S23, S24, S25, S26, S27, S28, S29, S30, S31, S32, S33, S34, S35, S36, S37, S38, S39, S40, S41, S42, S43, S44, S45, S46, S47, S48, S49, S50, S51, S52, S53, S54, S56, S57, S59, S60, S61, S62: Keyswitch; Choc_V1; not fitted
S55, S58: Keyswitch; Choc_V1_2.00u; not fitted
U1: Raspberry_Pi_Pico; not fitted
U2: PinHeader_1x04_P2.54mm_Vertical; not fitted

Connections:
3V3: U1.36 (3V3), U2.2 (VIN)
Column 0: S1.1, S15.1, S27.1, S39.1, S51.1, U1.20 (GPIO15)
Column 1: S2.1, S16.1, S28.1, S40.1, S52.1, U1.19 (GPIO14)
Column 2: S3.1, S17.1, S29.1, S41.1, S53.1, U1.17 (GPIO13)
Column 3: S4.1, S18.1, S30.1, S42.1, S54.1, U1.16 (GPIO12)
Column 4: S5.1, S19.1, S31.1, S43.1, S55.1, U1.15 (GPIO11)
Column 5: S6.1, S20.1, S32.1, S44.1, S56.1, U1.14 (GPIO10)
Column 6: S7.1, U1.12 (GPIO9)
Column 7: S8.1, U1.29 (GPIO22)
Column 8: S9.1, S21.1, S33.1, S45.1, S57.1, U1.27 (GPIO21)
Column 9: S10.1, S22.1, S34.1, S46.1, S58.1, U1.26 (GPIO20)
Column 10: S11.1, S23.1, S35.1, S47.1, S59.1, U1.25 (GPIO19)
Column 11: S12.1, S24.1, S36.1, S48.1, S60.1, U1.24 (GPIO18)
Column 12: S13.1, S25.1, S37.1, S49.1, S61.1, U1.22 (GPIO17)
Column 13: S14.1, S26.1, S38.1, S50.1, S62.1, U1.21 (GPIO16)
GND: U1.3 (GND), U1.8 (GND), U1.13 (GND), U1.18 (GND), U1.23 (GND), U1.28 (GND), U1.38 (GND), U2.1 (GND)
unnamed: D1.2 (A), S1.2
unnamed: D2.2 (A), S2.2
unnamed: D3.2 (A), S3.2
unnamed: D4.2 (A), S4.2
unnamed: D5.2 (A), S5.2
unnamed: D6.2 (A), S6.2
unnamed: D7.2 (A), S7.2
unnamed: D8.2 (A), S8.2
unnamed: D9.2 (A), S9.2
unnamed: D10.2 (A), S10.2
unnamed: D11.2 (A), S11.2
unnamed: D12.2 (A), S12.2
unnamed: D13.2 (A), S13.2
unnamed: D14.2 (A), S14.2
unnamed: D15.2 (A), S15.2
unnamed: D16.2 (A), S16.2
unnamed: D17.2 (A), S17.2
unnamed: D18.2 (A), S18.2
unnamed: D19.2 (A), S19.2
unnamed: D20.2 (A), S20.2
unnamed: D21.2 (A), S21.2
unnamed: D22.2 (A), S22.2
unnamed: D23.2 (A), S23.2
unnamed: D24.2 (A), S24.2
unnamed: D25.2 (A), S25.2
unnamed: D26.2 (A), S26.2
unnamed: D27.2 (A), S27.2
unnamed: D28.2 (A), S28.2
unnamed: D29.2 (A), S29.2
unnamed: D30.2 (A), S30.2
unnamed: D31.2 (A), S31.2
unnamed: D32.2 (A), S32.2
unnamed: D33.2 (A), S33.2
unnamed: D34.2 (A), S34.2
unnamed: D35.2 (A), S35.2
unnamed: D36.2 (A), S36.2
unnamed: D37.2 (A), S37.2
unnamed: D38.2 (A), S38.2
unnamed: D39.2 (A), S39.2
unnamed: D40.2 (A), S40.2
unnamed: D41.2 (A), S41.2
unnamed: D42.2 (A), S42.2
unnamed: D43.2 (A), S43.2
unnamed: D44.2 (A), S44.2
unnamed: D45.2 (A), S45.2
unnamed: D46.2 (A), S46.2
unnamed: D47.2 (A), S47.2
unnamed: D48.2 (A), S48.2
unnamed: D49.2 (A), S49.2
unnamed: D50.2 (A), S50.2
unnamed: D51.2 (A), S51.2
unnamed: D52.2 (A), S52.2
unnamed: D53.2 (A), S53.2
unnamed: D54.2 (A), S54.2
unnamed: D55.2 (A), S55.2
unnamed: D56.2 (A), S56.2
unnamed: D57.2 (A), S57.2
unnamed: D58.2 (A), S58.2
unnamed: D59.2 (A), S59.2
unnamed: D60.2 (A), S60.2
unnamed: D61.2 (A), S61.2
unnamed: D62.2 (A), S62.2
Row 0: D1.1 (K), D2.1 (K), D3.1 (K), D4.1 (K), D5.1 (K), D6.1 (K), D7.1 (K), D8.1 (K), D9.1 (K), D10.1 (K), D11.1 (K), D12.1 (K), D13.1 (K), D14.1 (K), U1.1 (GPIO0)
Row 1: D15.1 (K), D16.1 (K), D17.1 (K), D18.1 (K), D19.1 (K), D20.1 (K), D21.1 (K), D22.1 (K), D23.1 (K), D24.1 (K), D25.1 (K), D26.1 (K), U1.2 (GPIO1)
Row 2: D27.1 (K), D28.1 (K), D29.1 (K), D30.1 (K), D31.1 (K), D32.1 (K), D33.1 (K), D34.1 (K), D35.1 (K), D36.1 (K), D37.1 (K), D38.1 (K), U1.9 (GPIO6)
Row 3: D39.1 (K), D40.1 (K), D41.1 (K), D42.1 (K), D43.1 (K), D44.1 (K), D45.1 (K), D46.1 (K), D47.1 (K), D48.1 (K), D49.1 (K), D50.1 (K), U1.10 (GPIO7)
Row 4: D51.1 (K), D52.1 (K), D53.1 (K), D54.1 (K), D55.1 (K), D56.1 (K), D57.1 (K), D58.1 (K), D59.1 (K), D60.1 (K), D61.1 (K), D62.1 (K), U1.11 (GPIO8)
SCL: U1.5 (GPIO3), U2.3 (SCL)
SDA: U1.4 (GPIO2), U2.4 (SDA)

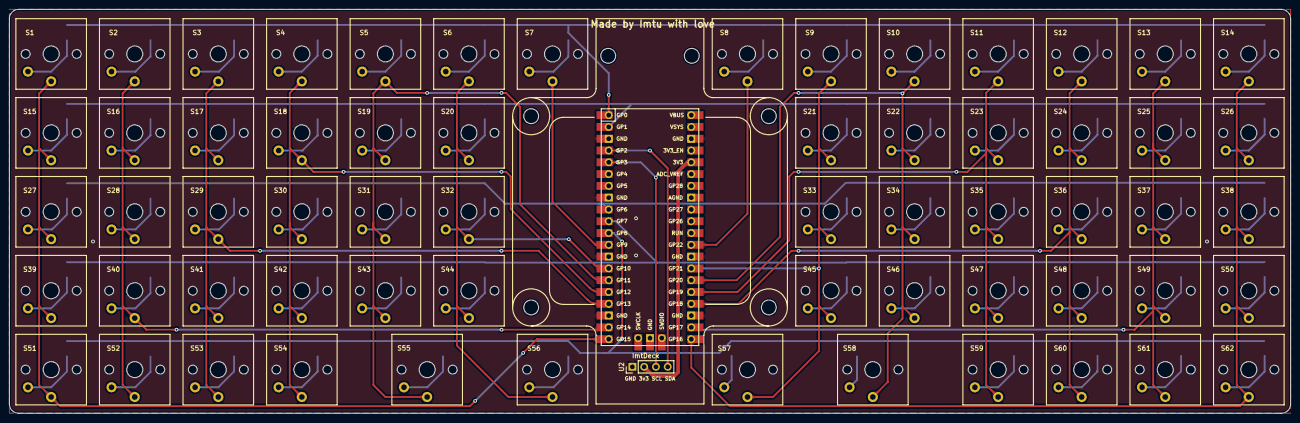
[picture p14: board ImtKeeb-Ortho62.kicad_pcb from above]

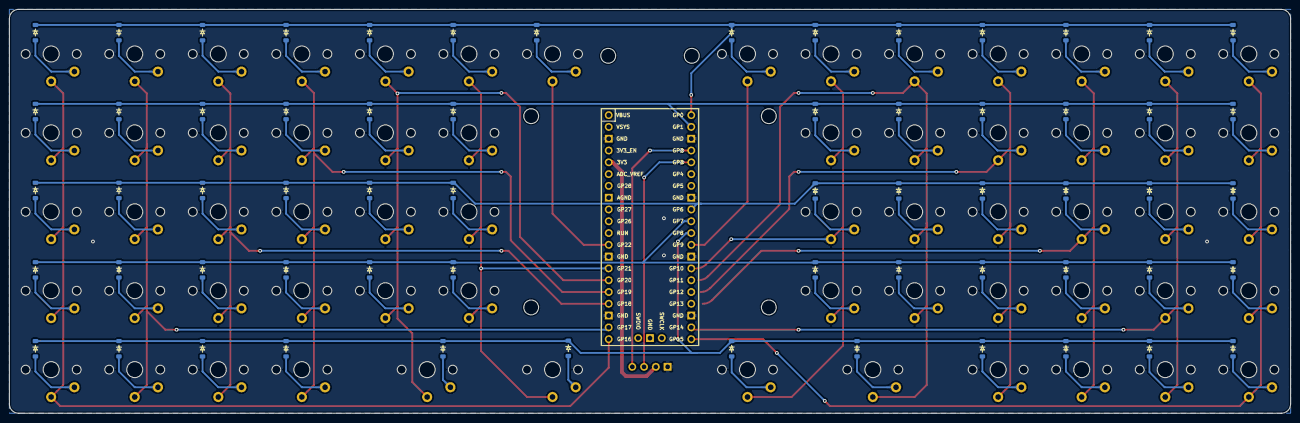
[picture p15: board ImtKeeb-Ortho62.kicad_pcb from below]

Board: 2 copper layers, 276.0 x 87.0 mm, 126 parts (62 on the bottom side), 85 nets.

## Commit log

2026-08-27 Keyboard PCB
2026-08-28 Started from Nothing
    [2086581001.step, 2086581001.stp, 48406-0001.stp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]
2026-08-28 3d files of ImtDeck
    [ImtDeck Case.step, ImtDeck Metal Parts.step, ImtDeck Printed Parts.step]
2026-08-28 ImtDeck BOM
    [ImtDeck BOM.csv]
